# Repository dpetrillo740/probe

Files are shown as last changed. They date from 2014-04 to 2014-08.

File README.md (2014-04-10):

probe
=====

A smart thermometer probe built on top of spark.io, made by Dave Petrillo

These files have been made available online through a Creative Commons Attribution-ShareAlike 3.0 license.

You are welcome to distribute, remix, and use these files for commercial purposes. If you do so, please attribute the original design to us both on the website and on the physical packaging of the product or in the instruction manual. All derivative works must be published under the same or a similar license.

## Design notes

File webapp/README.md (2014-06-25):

# angular-seed — the seed for AngularJS apps

This project is an application skeleton for a typical [AngularJS](http://angularjs.org/) web app.
You can use it to quickly bootstrap your angular webapp projects and dev environment for these
projects.

The seed contains a sample AngularJS application and is preconfigured to install the Angular
framework and a bunch of development and testing tools for instant web development gratification.

The seed app doesn't do much, just shows how to wire two controllers and views together.

## Getting Started

To get you started you can simply clone the angular-seed repository and install the dependencies:

### Clone angular-seed

Clone the angular-seed repository using [git][git]:

```
git clone https://github.com/angular/angular-seed.git
cd angular-seed
```

### Install Dependencies

We have two kinds of dependencies in this project: tools and angular framework code.  The tools help
us manage and test the application.

* We get the tools we depend upon via `npm`, the [node package manager][npm].
* We get the angular code via `bower`, a [client-side code package manager][bower].

We have preconfigured `npm` to automatically run `bower` so we can simply do:

```
npm install
```

Behind the scenes this will also call `bower install`.  You should find that you have two new
folders in your project.

* `node_modules` - contains the npm packages for the tools we need
* `bower_components` - contains the angular framework files

### Run the Application

We have preconfigured the project with a simple development web server.  The simplest way to start
this server is:

```
npm start
```

Now browse to the app at `http://localhost:8000/app/index.html`.

## Directory Layout

    app/                --> all of the files to be used in production
      css/              --> css files
        app.css         --> default stylesheet
      img/              --> image files
      index.html        --> app layout file (the main html template file of the app)
      index-async.html  --> just like index.html, but loads js files asynchronously
      js/               --> javascript files
        app.js          --> application
        controllers.js  --> application controllers
        directives.js   --> application directives
        filters.js      --> custom angular filters
        meatDefinitionService.js     --> custom angular services
      partials/             --> angular view partials (partial html templates)
        partial1.html
        partial2.html

    test/               --> test config and source files
      protractor-conf.js    --> config file for running e2e tests with Protractor
      e2e/                  --> end-to-end specs
        scenarios.js
      karma.conf.js         --> config file for running unit tests with Karma
      unit/                 --> unit level specs/tests
        controllersSpec.js      --> specs for controllers
        directivessSpec.js      --> specs for directives
        filtersSpec.js          --> specs for filters
        servicesSpec.js         --> specs for services

## Testing

There are two kinds of tests in the angular-seed application: Unit tests and End to End tests.

### Running Unit Tests

The angular-seed app comes preconfigured with unit tests. These are written in
[Jasmine][jasmine], which we run with the [Karma Test Runner][karma]. We provide a Karma
configuration file to run them.

* the configuration is found at `test/karma.conf.js`
* the unit tests are found in `test/unit/`.

The easiest way to run the unit tests is to use the supplied npm script:

```
npm test
```

This script will start the Karma test runner to execute the unit tests. Moreover, Karma will sit and
watch the source and test files for changes and then re-run the tests whenever any of them change.
This is the recommended strategy; if you unit tests are being run every time you save a file then
you receive instant feedback on any changes that break the expected code functionality.

You can also ask Karma to do a single run of the tests and then exit.  This is useful if you want to
check that a particular version of the code is operating as expected.  The project contains a
predefined script to do this:

```
npm run test-single-run
```

### End to end testing

The angular-seed app comes with end-to-end tests, again written in [Jasmine][jasmine]. These tests
are run with the [Protractor][protractor] End-to-End test runner.  It uses native events and has
special features for Angular applications.

* the configuration is found at `test/protractor-conf.js`
* the end-to-end tests are found in `test/e2e/`

Protractor simulates interaction with our web app and verifies that the application responds
correctly. Therefore, our web server needs to be serving up the application, so that Protractor
can interact with it.

```
npm start
```

In addition, since Protractor is built upon WebDriver we need to install this.  The angular-seed
project comes with a predefined script to do this:

```
npm run update-webdriver
```

This will download and install the latest version of the stand-alone WebDriver tool.

Once you have ensured that the development web server hosting our application is up and running
and WebDriver is updated, you can run the end-to-end tests using the supplied npm script:

```
npm run protractor
```

This script will execute the end-to-end tests against the application being hosted on the
development server.

## Updating Angular

Previously we recommended that you merge in changes to angular-seed into your own fork of the project.
Now that the angular framework library code and tools are acquired through package managers (npm and
bower) you can use these tools instead to update the dependencies.

You can update the tool dependencies by running:

```
npm update
```

This will find the latest versions that match the version ranges specified in the `package.json` file.

You can update the Angular dependencies by running:

```
bower update
```

This will find the latest versions that match the version ranges specified in the `bower.json` file.

## Loading Angular Asynchronously

The angular-seed project supports loading the framework and application scripts asynchronously.  The
special `index-async.html` is designed to support this style of loading.  For it to work you must
inject a piece of Angular JavaScript into the HTML page.  The project has a predefined script to help
do this.

```
npm run update-index-async
```

This will copy the contents of the `angular-loader.js` library file into the `index-async.html` page.
You can run this every time you update the version of Angular that you are using.

## Serving the Application Files

While angular is client-side-only technology and it's possible to create angular webapps that
don't require a backend server at all, we recommend serving the project files using a local
webserver during development to avoid issues with security restrictions (sandbox) in browsers. The
sandbox implementation varies between browsers, but quite often prevents things like cookies, xhr,
etc to function properly when an html page is opened via `file://` scheme instead of `http://`.

### Running the App during Development

The angular-seed project comes preconfigured with a local development webserver.  It is a node.js
tool called [http-server][http-server].  You can start this webserver with `npm start` but you may choose to
install the tool globally:

```
sudo npm install -g http-server
```

Then you can start your own development web server to server static files, from a folder, by
running:

```
http-server
```

Alternatively, you can choose to configure your own webserver, such as apache or nginx. Just
configure your server to serve the files under the `app/` directory.

### Running the App in Production

This really depends on how complex is your app and the overall infrastructure of your system, but
the general rule is that all you need in production are all the files under the `app/` directory.
Everything else should be omitted.

Angular apps are really just a bunch of static html, css and js files that just need to be hosted
somewhere, where they can be accessed by browsers.

If your Angular app is talking to the backend server via xhr or other means, you need to figure
out what is the best way to host the static files to comply with the same origin policy if
applicable. Usually this is done by hosting the files by the backend server or through
reverse-proxying the backend server(s) and webserver(s).

## Continuous Integration

### Travis CI

[Travis CI][travis] is a continuous integration service, which can monitor GitHub for new commits
to your repository and execute scripts such as building the app or running tests. The angular-seed
project contains a Travis configuration file, `.travis.yml`, which will cause Travis to run your
tests when you push to GitHub.

You will need to enable the integration between Travis and GitHub. See the Travis website for more
instruction on how to do this.

### CloudBees

CloudBees have provided a CI/deployment setup:

<a href="https://grandcentral.cloudbees.com/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">
</a>

If you run this, you will get a cloned version of this repo to start working on in a private git repo,
along with a CI service (in Jenkins) hosted that will run unit and end to end tests in both Firefox and Chrome.

## Contact

For more information on AngularJS please check out http://angularjs.org/

[git]: http://git-scm.com/
[bower]: http://bower.io
[npm]: https://www.npmjs.org/
[node]: http://nodejs.org
[protractor]: https://github.com/angular/protractor
[jasmine]: http://pivotal.github.com/jasmine/
[karma]: http://karma-runner.github.io
[travis]: https://travis-ci.org/
[http-server]: https://github.com/nodeapps/http-server

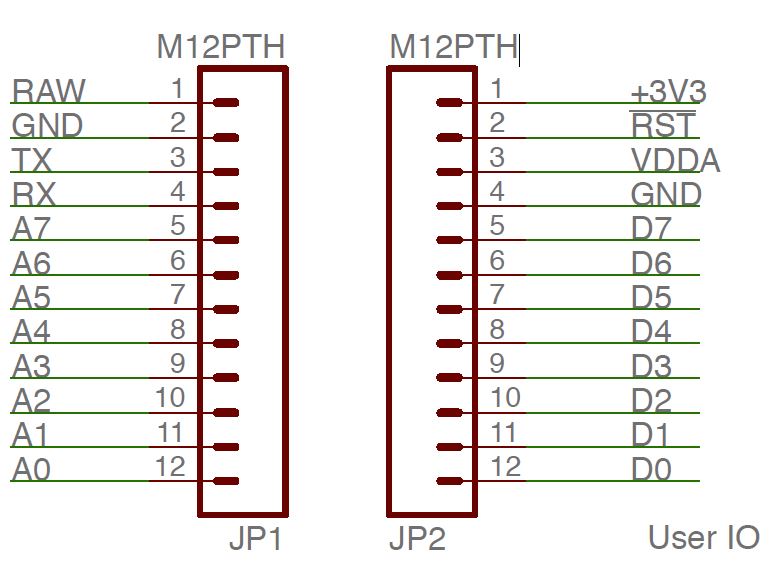
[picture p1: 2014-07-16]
SparkIO Thermal Shield/Documentation/SparkIO Core PDFs/SparkIO Headers.JPG

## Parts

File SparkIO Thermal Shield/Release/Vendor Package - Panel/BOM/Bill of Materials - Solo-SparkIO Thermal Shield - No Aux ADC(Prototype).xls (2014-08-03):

Item # | Designator | Fitted/Not Fitted | Quantity | Manufacturer | Manufacturer Part Number | Name | Supplier 1 | Supplier Part Number 1
1 | C1, C2, C3, C4, C5, C6 | Fitted | 6 | TDK Corporation | C1608X7R1E103K080AA | CAP CER 10000PF 25V 10% X7R 0603 | Digi-Key | 445-5100-1-ND
2 | C7, C8, C9, C10, C11, C12, C13 | Fitted | 7 | TDK Corporation | C1608X7R1C105K080AC | CAP CER 1UF 16V 10% X7R 0603 | Digi-Key | 445-1604-1-ND
3 | DS1 | Fitted | 1 | LiteOn | LTST-C190KGKT | Green LED 20mA 2V Vf | Digi-Key | 160-1435-1-ND
4 | H1, H2 | Fitted | 2 | Sullins Interconnect | PPTC121LFBN-RC | CONN HEADER FEM 12POS .1" SGL TIN | Digi-Key | S6100-ND
5 | J1, J2 | Fitted | 2 | Omega | PCC-SMP-K | K Type Thermocouple Mini Horizontal TH Connector | Newark | 01H0905
6 | J3, J4 | Fitted | 2 | CUI Inc | MJ-2509N | 3/32" Mono Audio Jack Right Angle TH | Digi-Key | CP-M2509N-ND
7 | R1, R8, R13, R18 | Fitted | 4 | Vishay | CRCW0603100KFKEA | RES 100K OHM 1/10W 1% 0603 SMD | Digi-Key | 541-100KHCT-ND
8 | R2, R7, R10, R15 | Fitted | 4 | Vishay | CRCW060322K0FKEA | RES 22.0K OHM 1/10W 1% 0603 SMD | Digi-Key | 541-22.0KHCT-ND
9 | R3, R5, R9, R11, R19 | Fitted | 5 | Vishay | CRCW06031K00FKEA | RES 1.00K OHM 1/10W 1% 0603 SMD | Digi-Key | 541-1.00KHCT-ND
10 | R4, R6, R12, R14, R16, R17 | Fitted | 6 | Vishay | CRCW060310K0FKEA | RES 10.0K OHM 1/10W 1% 0603 SMD | Digi-Key | 541-10.0KHCT-ND
11 | TB1, TB2 | Fitted | 2 | On Shore Technology | OSTTE120104 | TERMINAL BLOCK 3.5MM 12POS PCB | Digi-Key | ED2737-ND
12 | U1, U2 | Fitted | 2 | Texas Instruments | OPA2376AIDR | IC Op Amp Dual GBP 5.5MHz 8SOIC | Digi-Key | 296-22564-1-ND
13 | U3 | Fitted | 1 | Microchip | TC1046VNBTR | Precision Temperature Sensing IC | Digi-Key | TC1046VNBTRCT-ND

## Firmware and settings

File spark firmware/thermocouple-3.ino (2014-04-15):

double thermoTemp = 0;
double internalTemp = 0;
double debug = 0;
bool hasError = false;
bool scvFault = false;
bool scgFault = false;
bool ocFault = false;
unsigned long raw = 0;
int st;
double setPoint;
String cookType;
double heatSourceTemp;
double meatMass;
String meatType;
double meatDim;
double maxtemp = 0;
double t0;
double t1;
double t2;
double t3;

typedef struct {
    int ThermoTemp : 14;
    unsigned char Reserved : 1;
    bool Fault : 1;
    int InternalTemp : 12;
    unsigned char Reserved2 : 1;
    bool SCVFault : 1;
    bool SCGFault : 1;
    bool OCFault : 1; 
} Temp;

union Reading {
  unsigned long bit32;
  unsigned int bit16[2];
  unsigned char bit8[4];
  Temp temp;
};

char resultstr[64];

int cookFunction(String command);

void setup() {
    
  pinMode(D0,OUTPUT);    //Set these pins to output for CS0-3
  pinMode(D1,OUTPUT);    
  pinMode(D2,OUTPUT);    
  pinMode(D3,OUTPUT);    

  pinMode(D7,OUTPUT);       
  
  Serial.begin(9600);        
  
  Serial.println("MAX31855 test");
  // wait for MAX chip to stabilize
  delay(1000);
  
    Spark.variable("hasError", &hasError, BOOLEAN);
    Spark.variable("scvFault", &scvFault, BOOLEAN);
    Spark.variable("scgFault", &scgFault, BOOLEAN);
    Spark.variable("ocFault", &ocFault, BOOLEAN);
    Spark.variable("thermoTemp", &thermoTemp, DOUBLE);
    Spark.variable("internalTemp", &internalTemp, DOUBLE);
    Spark.variable("raw", &raw, INT);
    Spark.variable("result", &resultstr, STRING); 
    //add spark vairable to debug remotely 
    Spark.variable("debug", &debug, DOUBLE);

    SPI.setClockDivider(SPI_CLOCK_DIV64);
    SPI.setBitOrder(MSBFIRST);
    SPI.setDataMode(SPI_MODE3);
    SPI.begin();
    
    Spark.function("cook", cookFunction);
    
    digitalWrite(D0, HIGH);
    digitalWrite(D1, HIGH);
    digitalWrite(D2, HIGH);
    digitalWrite(D3, HIGH);
    

}

void loop() {
    
    // Wiring instructions for playing with fusion 4ch thermocouple board 
    //Connect SO to A4
    //Connect SCK to A3
    //CS0-3 to D0-3
    

    
    t0 = readChip(0,true);
    t1 = readChip(1,true);
    t2 = readChip(2,true);
    t3 = readChip(3,true);
    
    
    if (t3 > maxtemp){
        maxtemp = t3;
    }
    
    Serial.print("The max temp recorded so far is:");
    Serial.print(maxtemp);
    Serial.println("");   
    
    sprintf(resultstr, "{\"t2\":%f,\"t3\":%f}", t2, t3); 
    delay(1000);
    
    Spark.publish("Temp", String(t3));
    

    
    if (setPoint && (t3 > setPoint)) {
    Serial.print("The measured temp exceeds the setpoint");
    Serial.println("");    
    digitalWrite(D7,HIGH);   
    }
}

double readChip(int chip, bool print){
//read the temperature from the thermocouple connected to 'chip'
//print the data to the serial port if print is true
    Reading reading;
    
    //clear the data
    reading.bit32 = 0;
    
    digitalWrite(("D",chip), LOW);
    delay(5);

    //read in the 32-bit value
    for(int i =3; i >= 0 ; i--) {
        reading.bit8[i] = SPI.transfer(0);
    }

    thermoTemp = (0x80000000 & reading.bit32 ? -1.0 : 1.0) * (double)((reading.bit32 >> 18) & 0x00001FFF) / 4.0;
    internalTemp =(0x00008000 & reading.bit32 ? -1.0 : 1.0) * (double)((reading.bit32 >> 4) & 0x000007FF) / 16.0;

    hasError = reading.temp.Fault;
    scvFault = reading.temp.SCVFault;
    scgFault = reading.temp.SCGFault;
    ocFault = reading.temp.OCFault;
    raw = reading.bit32;

    digitalWrite(("D",chip), HIGH);
    
    double tempF;
    tempF =  ((float)thermoTemp*9.0/5.0+32.0);
    
    if (print == true) {
      Serial.print("T");
      Serial.print(chip);
      Serial.print(" = ");
      Serial.print(tempF);
      Serial.print(" F");
      Serial.println(""); 
    }
    delay(10);
    return tempF;
}

//This is the 'spark fucntion' that accepts the POST command from our Google App Script
int cookFunction(String command) 
{

  //Change the data recieved to a char    
  char *charCommand; 
  charCommand = strdup(command.c_str());
  //Initialize a helper variable to be used with strtok_r
  char *saveptr;
  
  //Parse the recieved command into usable local variables
  setPoint = strtod(strtok_r(charCommand, ",", &saveptr), NULL);
 // debug = strtod(strtok_r(charCommand, ",", &saveptr), NULL);
  cookType = strtok_r(NULL, ",", &saveptr);
  heatSourceTemp = strtod(strtok_r(NULL, ",", &saveptr), NULL);
  meatMass = strtod(strtok_r(NULL, ",", &saveptr), NULL);
  meatType = strtok_r(NULL, ",", &saveptr);
  meatDim = strtod(strtok_r(NULL, ",", &saveptr), NULL);
  
  Serial.print("The set temp is: ");
  Serial.print(setPoint);
  Serial.println("");
  Serial.print("The cooking method is: ");
  Serial.print(cookType);
  Serial.println("");
  Serial.print("The source temp is: ");
  Serial.print(heatSourceTemp);
  Serial.println("");
  Serial.print("The meat mass is: ");
  Serial.print(meatMass);
  Serial.println("");
  Serial.print("The meat type is: ");
  Serial.print(meatType);
  Serial.println("");
  Serial.print("The meat dimension is: ");
  Serial.print(meatDim);
  Serial.println("");  
  
  
  //This section could execute a function that contained models when the cook command was recieved
  //Right now it does not do anything
  //The return of this function is the reply sent to the POST command and can pass data back to the App Script
  //look for the matching argument "cooknow" <-- max of 64 characters long
  if(command == "cooknow")
  {
    Serial.print("Cook Command Recieved!");
    return 1;
  }
  else return -1;
}

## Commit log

2014-04-12 fixed issues parsing data from google forms
    [thermocouple-3.ino]
2014-07-16 Initial sync of all analog solution
    This electronics variant is an all analog solution which provides
    filtered analog amplifiers for thermocouple inputs, and utilizes the
    built-in ADC on the Spark core itself.
    Also synced some documentation on thermocouple sensing.
    Purposefully selected some multi-purpose I/O on the spark core for ADC
    inputs such that the SPI interface is left intact.
    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
    [SparkIO Thermal Shield - No Aux ADC.SchDoc, SparkIO Thermal Shield.PrjPCB, core-pin-mapping-v1.xlsx]
2014-07-16 Schematic Complete, Component Selection Complete
    Next step is reviewing schematic to make sure it meets requirements,
    reviewing components to ensure they are adequate for the solution, then
    generating footprints for oddball connectors.
    [SparkIO Thermal Shield - No Aux ADC.SchDoc, SparkIO Thermal Shield.PrjPCB]
2014-07-16 Added terminal blocks
    LoL added terminal blocks for improved prototyping.
    Considering alternative linear regulator to run off of this board as an
    alternative power feed. Also considering external power feed and MOSFETs
    to switch external loads such as fans, lights, etc.
    [SparkIO Thermal Shield - No Aux ADC.SchDoc, SparkIO Thermal Shield.PrjPCB]
2014-07-17 Adding gitignore for Altium files
    Still fixing BOM PDF
    [SparkIO Thermal Shield.PrjPCB]
2014-07-17 PDF Generated with BOM
    Cleaned up the BOM template so it's readable.
    First full generation of schematic and BOM in the Output PDF.
2014-07-24 Footprints done, starting placement
    [SparkIO Thermal Shield - No Aux ADC.SchDoc, SparkIO Thermal Shield.PcbDoc, SparkIO Thermal Shield.PrjPCB]
2014-07-24 Worked on it twerked on it - placement
    [SparkIO Thermal Shield - No Aux ADC.SchDoc, SparkIO Thermal Shield.PcbDoc]
2014-07-26 PCB placement and silk complete
    Need to route and define stackup
    [SparkIO Thermal Shield - No Aux ADC.SchDoc, SparkIO Thermal Shield.PcbDoc, SparkIO Thermal Shield.PrjPCB]
2014-07-26 Routing complete, finalizing files
    Moved some ADC pins around and cleaned up routing, was able to get this
    down to a 2 layer PCB. Most of bottom layer is ground plane.
    Had to change 0603 package to remove silk as silk to soldermask
    clearance was annoying.
    No DRC errors.
    Generated drill table and eliminated a drill size for mounting stubs
    under thermistor audio jacks.
    Need to generate vendor files.
    [SparkIO Thermal Shield - No Aux ADC.SchDoc, SparkIO Thermal Shield.PcbDoc]
2014-07-28 Solo and panelized designs done
    Time to generate review and vendor package files
    [SparkIO Thermal Shield - No Aux ADC.SchDoc, SparkIO Thermal Shield - Panelized.PcbDoc, SparkIO Thermal Shield - Solo PCB.PcbDoc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]
2014-07-28 Vendor files almost ready
    Output vendor package almost ready.
    [SparkIO Thermal Shield.PrjPCB]
2014-07-28 Final vendor package generated
    PCB is called CharPCB Rev A.
    Panel is a 50-up design, need to figure out if it's reasonable for a
    quick turn house to do full turn-key.
    Vendor package includes necessary renderings, gerber and OBD files,
    drill files, BOM, assembly, etc.
    Review PDF also generated for PCB.
    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
    [Bill of Materials - Solo-SparkIO Thermal Shield - No Aux ADC(Prototype).xls, Pick Place for SparkIO Thermal Shield - Panelized(Prototype).csv, Pick Place for S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]
2014-07-29 Prepping for Phoenix PCB
    Increased minimum via size from 10mil to 15mil as a cost-down for
    ordering from Phoenix PCB
    [SparkIO Thermal Shield - Panelized 18x24.PcbDoc, SparkIO Thermal Shield - Panelized.PcbDoc, SparkIO Thermal Shield - Solo PCB.PcbDoc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]
2014-08-01 Fixed BOM supplier links
    Need to re-generate vendor package with this correction. No change to
    layout or gerbers. Step file added to output job and generated.
    [SparkIO Thermal Shield - No Aux ADC.SchDoc, SparkIO Thermal Shield.PrjPCB]
2014-08-02 Updated female header strip
    Generated the step file again. Need to regenerate whole vendor package
    and then it's done.
    [SparkIO Thermal Shield - No Aux ADC.SchDoc, SparkIO Thermal Shield - Solo PCB.PcbDoc, SparkIO Thermal Shield.PcbDoc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]
2014-08-03 Final Vendor Package, Temperature Tables
    Full final vendor package generated.
    Made a temperature table document for thermocouple and voltage reference
    devices. Need thermistor datasheets before I can make those.
    [Bill of Materials - Solo-SparkIO Thermal Shield - No Aux ADC(Prototype).xls, CharPCB Temperature Table.xlsx, Pick Place for SparkIO Thermal Shield - Panelized 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]
